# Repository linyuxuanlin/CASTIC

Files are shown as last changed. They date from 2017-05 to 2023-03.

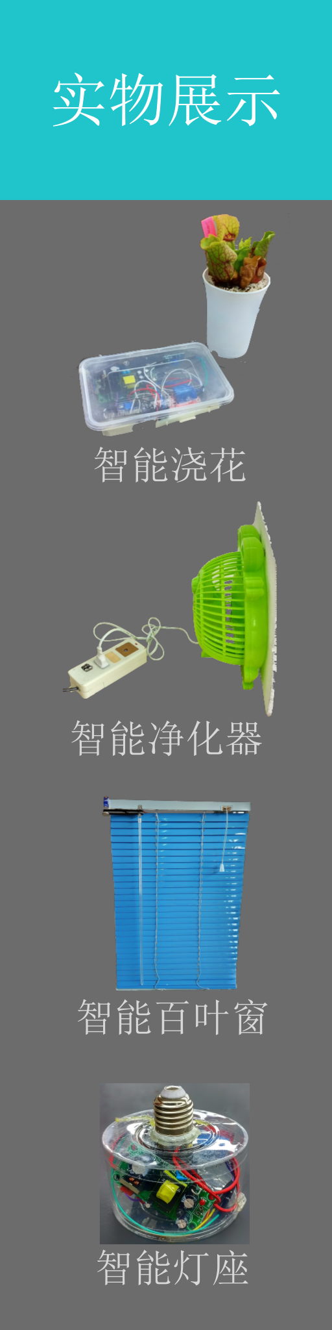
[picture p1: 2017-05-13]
展示宣传画/默认标题--设计创建于创客贴 (2).png

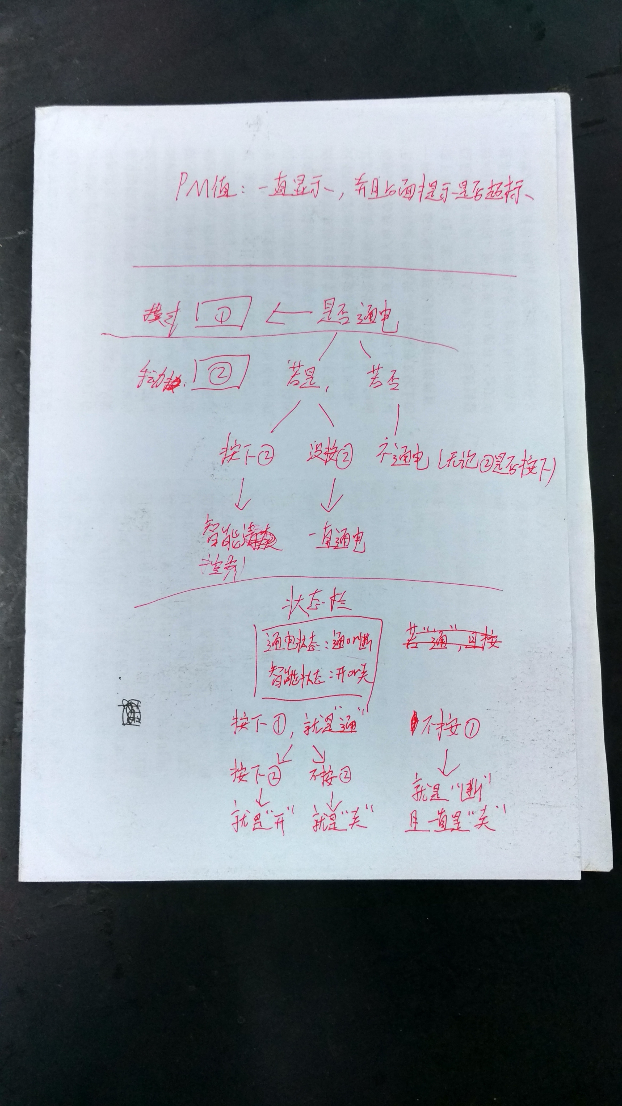
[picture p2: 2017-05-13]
废纸篓/想法构思/IMG_20161125_222327_HDR.jpg

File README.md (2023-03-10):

17年3月17日，我在广州执信中学参加了第32届科创省赛。
## 项目经过
* 项目开始于一年前。因为是团队与自己都从没接触过的新硬件和平台，所以经常会遇到代码编译出错、硬件调试失败之类的问题。虽然很多时候问题显而易见，却需要考虑到每一个小的改动与以后可能出现的重大问题的间接联系。
* 比赛的前几天，成品突然无故出了问题，如果不解决的话，肯定连三等奖都拿不上。团队的协作攻关在此时起到了重要的作用，在比赛前一天终于顺利把问题根除了。
* 比赛的时候，尽量要脸皮厚一些。这样才能拉到评委和嘉宾来参观自己的项目。解说的时候也要注意一定的技巧，比如，评委有时会提出刁难性的问题。这时只能顺着他的话锋，委婉地提出自己的观点，如此留给评委的印象会好很多，直接关系到自己的评分。
* 做出来的成品也交给专利代理事务所申请了专利，因为比赛的需要和日后可能的用处。

### 附：比赛现场的照片




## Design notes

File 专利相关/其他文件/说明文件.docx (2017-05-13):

一种智能家居无损升级方案，包括：智能百叶窗、智能空气净化器、智能灯座

1.智能百叶窗套件：普通的家用百叶窗，可以通过简单地加装我们的通用性模块，实现智能控制。

其特征在于：包括带esp8266WiFi功能的主控板(1)、DHT11温湿度传感器(2)、雨水传感器(3)、手动上升按钮(4)、手动下降按钮(5)、自动模式按钮(6)、自动状态指示灯(7)、控制百叶窗开合的舵机(8)。

主要功能：

1.通过检测空气湿度并判断是否下雨，自动控制百叶窗开合，保护家居；

2.百叶窗升级套件能够连接上家中的WiFi，使手机端app能够在任何地方看到百叶窗的开合状态、模式等并实现控制。手机app端能够获取家中的空气湿度，判断是否下雨并通知用户进行相关操作

3.百叶窗升级套件包含手动按钮(4、5)，分4个开合档位，可手动调节百叶窗开合程度

工作原理：

主控板(1)通过板载esp8266连接上WiFi，温湿度传感器(2)和雨水传感器(3)获取当前空气温湿度，按钮(4、5)为用户提供手动操作功能，舵机(8)控制百叶窗开合

2.智能空气净化器套件：包括智能插座、空气滤网。适用于大多数普通的家用电风扇改装成空气净化器。

其特征在于：包括带esp8266WiFi功能的主控板(1)、PM2.5传感器(2)、220v—5v降压模块(3)、继电器模块(4)、插座开关指示灯(5)。

主要功能：

插座能够连接上家中的WiFi，在手机app端能够实时显示家中PM2.5浓度值，判断是否超标并通知用户进行相关操作；自动模式下，如果空气浓度超标，智能插座能够使带有滤网的风扇运行，实现智能空气净化的目的

工作原理：

降压模块(2)将市电转换成5v电压为主控板(1)供电，主控板(1)通过板载esp8266连接上WiFi，PM2.5传感器(2)检测当前空气中的PM2.5浓度值，主控板(1)通过继电器(3)控制插座开关，指示灯(5)根据插座状态相应开关

3.智能灯座套件：普通的灯泡，可以通过加装通用性的智能灯座，实现智能控制。

其特征在于：包括带esp8266WiFi功能的主控板(1)、220v—5v降压模块(2)、继电器模块(3)、普通的灯泡(4)。

主要功能：智能灯座能够连上家中WiFi，实现手机app端的智能控制

工作原理：降压模块(2)将市电转换成5v电压为主控板(1)供电，主控板(1)通过板载esp8266连接上WiFi，主控板(1)通过继电器(3)控制灯泡开关

联动功能：

1.影院模式：当用户在手机app端点击影院模式时，百叶窗自动关合，空气净化器打开，灯泡熄灭，为用户模拟影院的环境

优势：

1.无损化：不破坏原有的家居结构，在其基础上加以智能化；

2.通用化：套件适配于大多数老旧家居结构

3.低成本化

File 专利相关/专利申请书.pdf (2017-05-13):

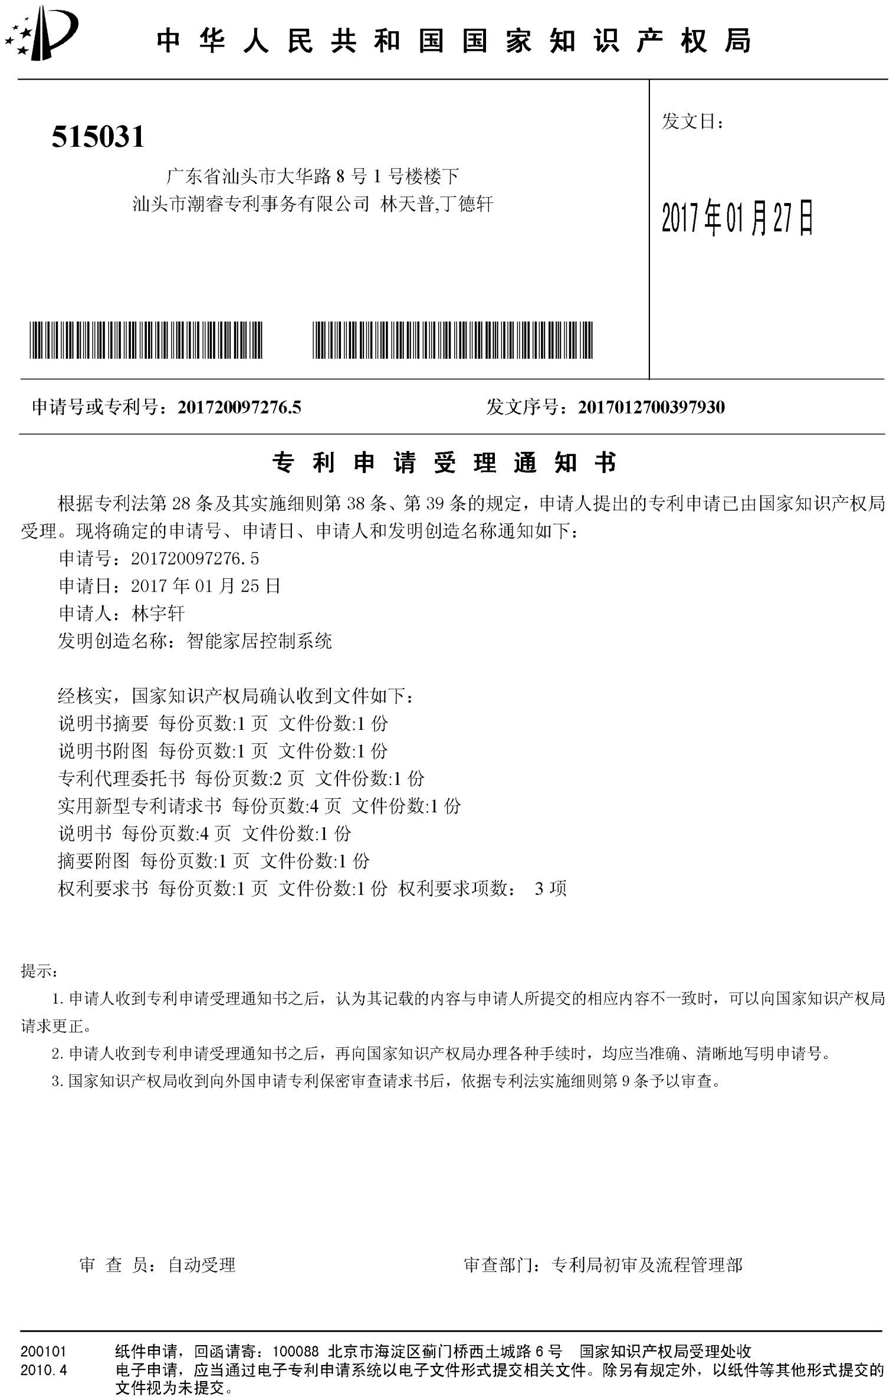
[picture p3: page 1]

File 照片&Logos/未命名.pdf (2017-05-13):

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

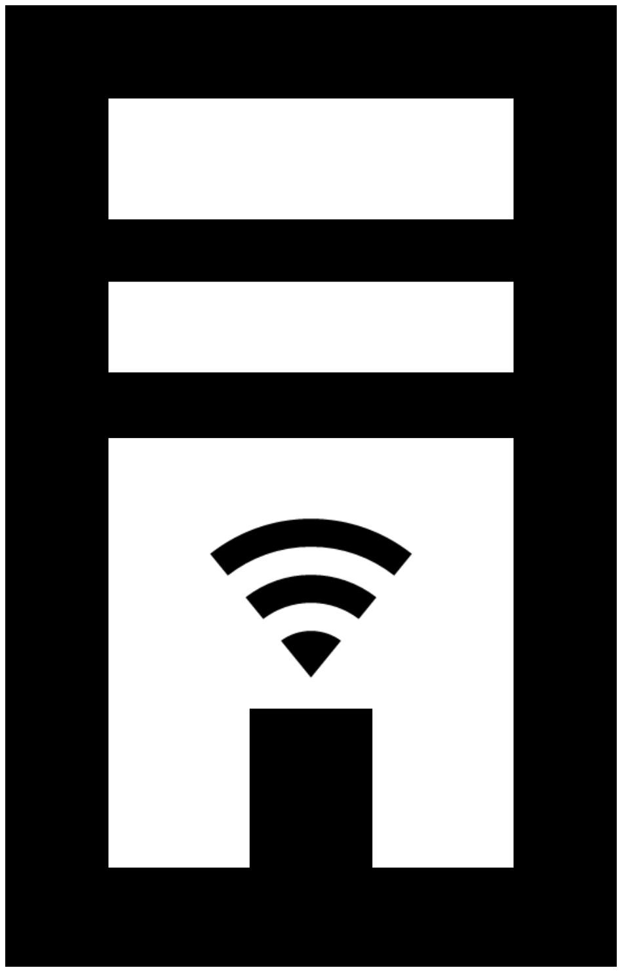
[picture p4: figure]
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

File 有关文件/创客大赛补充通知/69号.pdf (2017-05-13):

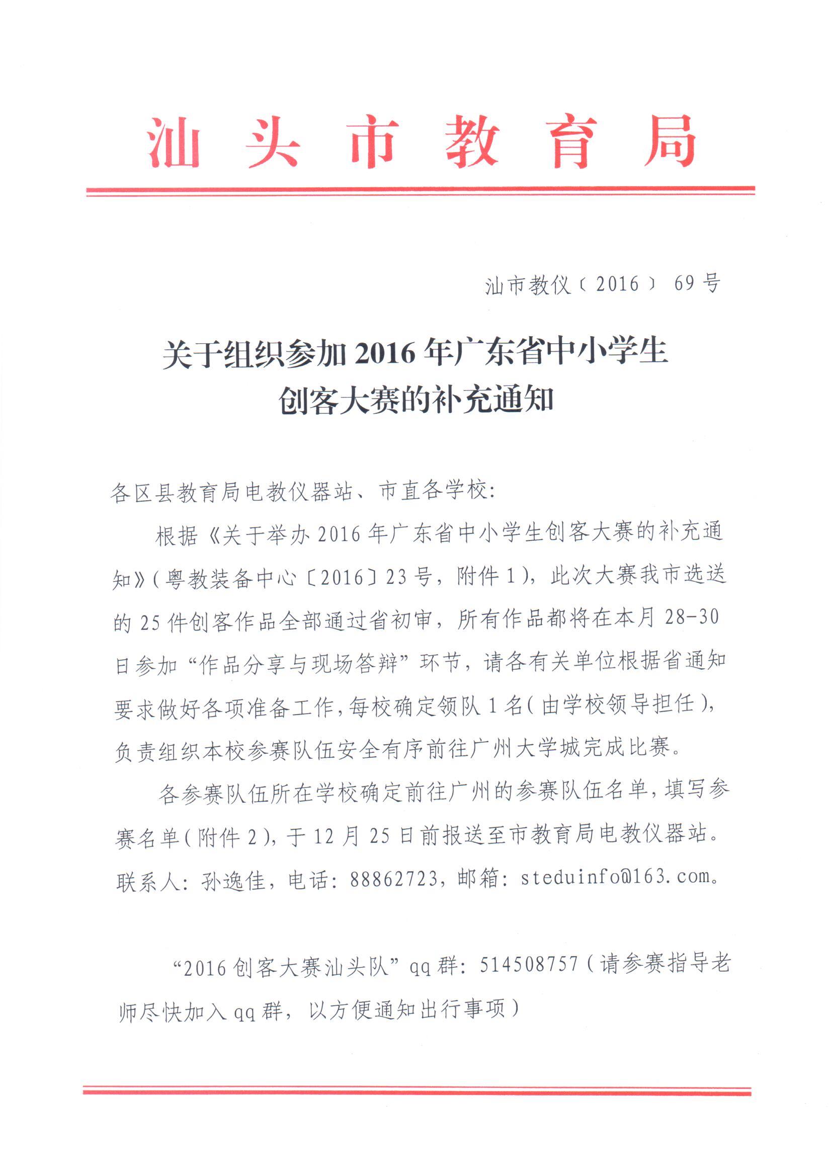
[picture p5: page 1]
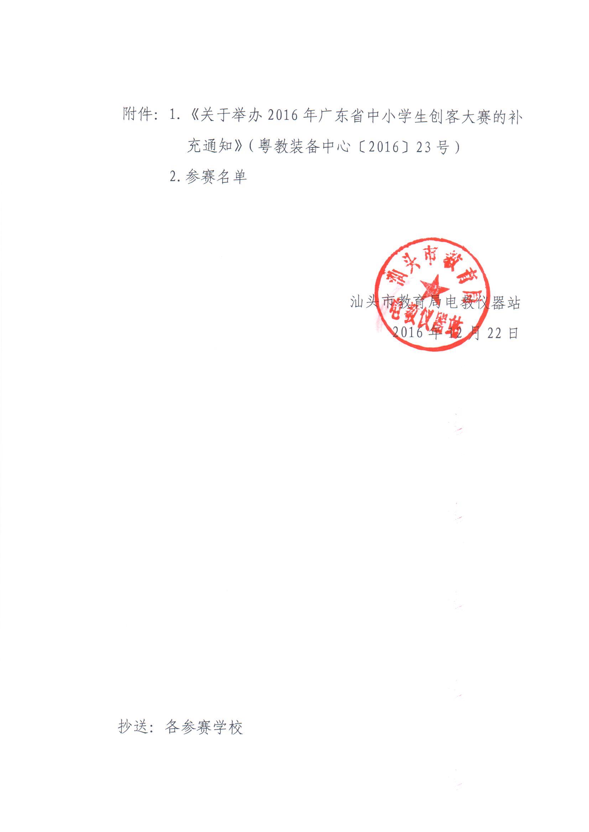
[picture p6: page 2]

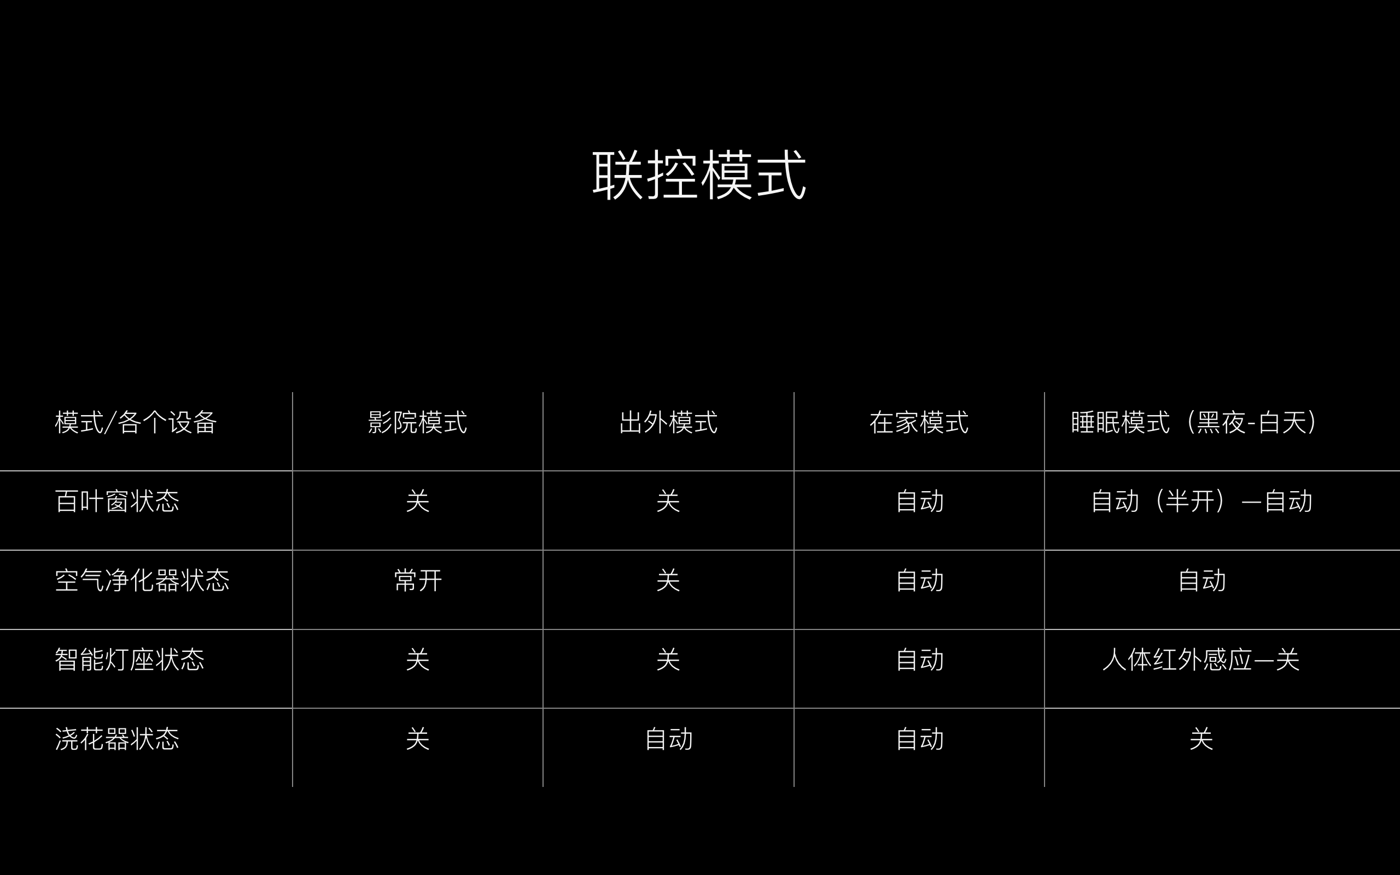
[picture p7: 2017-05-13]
联控模式.png

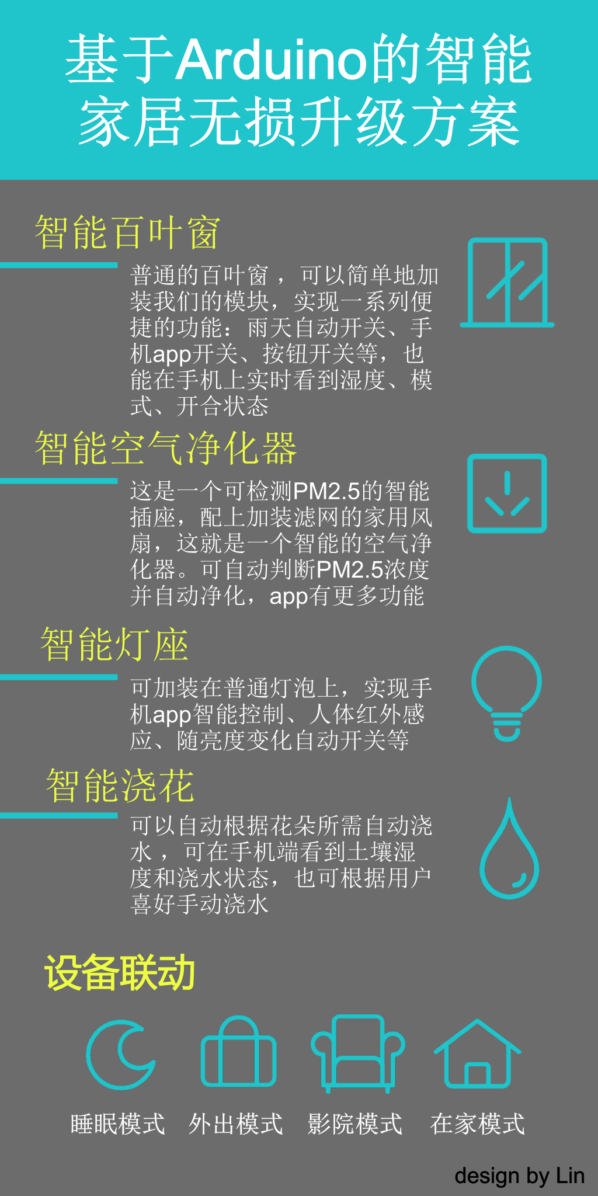
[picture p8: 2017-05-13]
展示宣传画/默认标题--设计创建于创客贴 (1).png

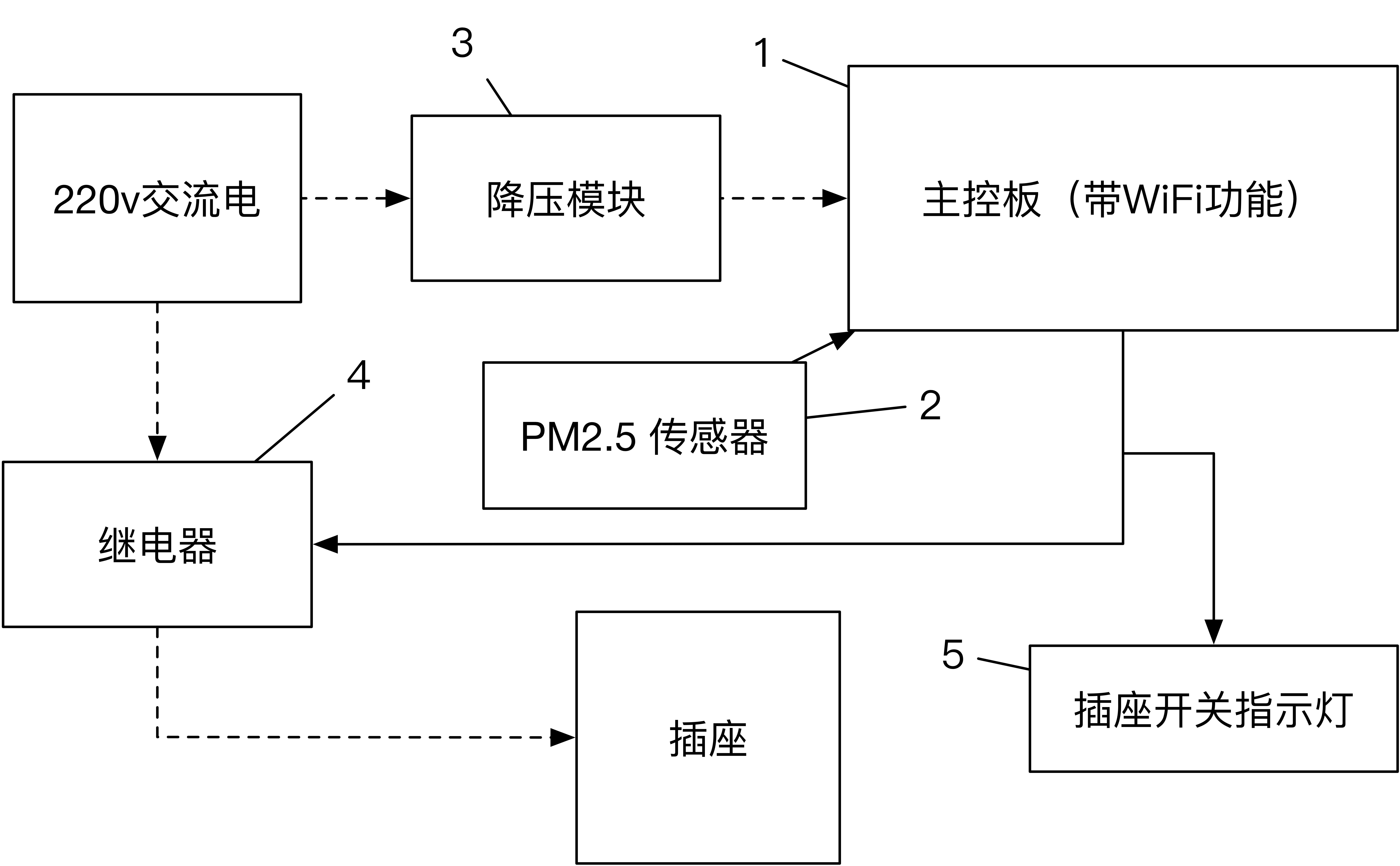
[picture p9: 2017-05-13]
专利相关/其他文件/插座流程图.png

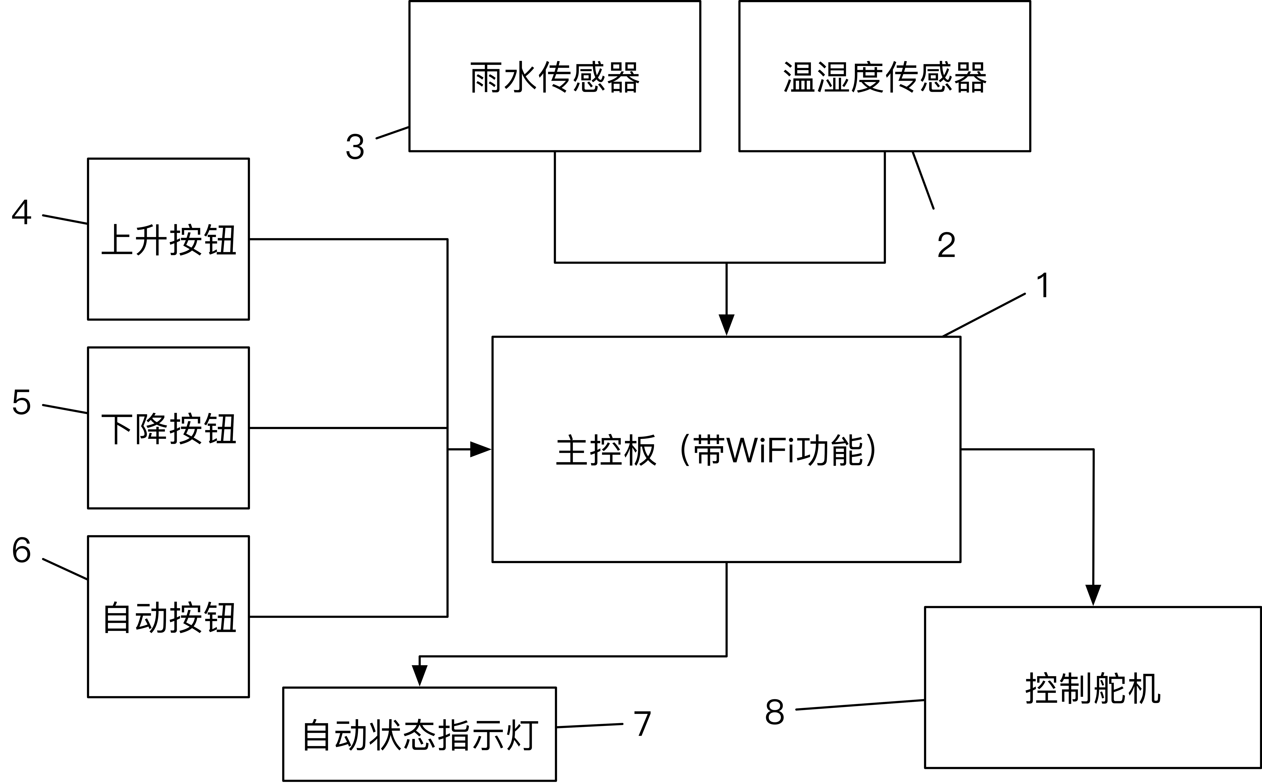
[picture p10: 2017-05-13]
专利相关/其他文件/百叶窗流程图.png

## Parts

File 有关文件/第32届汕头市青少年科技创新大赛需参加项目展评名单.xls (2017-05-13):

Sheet: 作品分类物理工程类
第32届汕头市青少年科技创新大赛项目展评名单（实践类）
申报单位：
项目编码 | 项 目 名 称 | 作 者 | 科技创新成果 | 所在学校 | 学历或年级 | 辅导教师 | 所属区域
A1 | 表面张力演示教具 | 陈新灏,郑枫辉 | 物理学 | 潮南区成田高级中学 | 高中 | 林彤妍 | 潮南区
A2 | 耳机绕线器 | 欧阳梓洪 | 物理学 | 潮南区两英中学 | 高中 | 陈丽玲 | 潮南区
A3 | 遥控重心平衡车 | 姚泽鹏 郑曼仪 陈潮锐 | 工程学 | 汕头市潮阳黄图盛中学 | 高中 | 陈镇宏 | 潮阳区
A4 | 诸葛连弩 | 陈新演 林自源 陈信宇 | 工程学 | 汕头市潮阳黄图盛中学 | 高中 | 李丽华 | 潮阳区
A5 | 四联一控开关 | 姚玫琼 | 工程学 | 汕头市潮阳黄图盛中学 | 高中 | 陈镇宏 | 潮阳区
A6 | 对生活慢速度陶瓷过滤器的改进 | 罗翊瀚 | 物理学 | 汕头市潮阳实验学校 | 初中 | 吴楷盛 王兴德 | 潮阳区
A7 | 多功能实时体温仪 | 刘煜凯 | 物理学 | 汕头市潮阳实验学校 | 初中 | 金邵涛 | 潮阳区
A8 | 粉笔粉尘环保收集盒 | 陈清钿 | 物理学 | 汕头市澄海莱芜中学 | 初中 | 许海得 | 澄海区
A9 | 可充电直流手电钻 | 杜中昊 | 物理学 | 澄海坝头中学 | 初中 | 王哲标 章逢媛 | 澄海区
A10 | 自动壁障吸尘器小汽车 | 蔡林宏 | 工程学 | 澄海凤翔中学 | 初中 | 林晓铭 李龙彦 | 澄海区
A11 | 安装超载自动报警器的货船 | 王思烁 程汤海 李穆羲 | 物理学 | 澄海区莲东中学 | 初中 | 肖锦豪 肖琼伟 | 澄海区
A12 | 地下车库进水报警及自动排水装置 | 陈勋 郭之泳 王思捷 | 物理学 | 澄海实验高级中学 | 高中 | 洪秋鹏 陈培顺 | 澄海区
A13 | 老年人服药提醒装置 | 刘伟雄 王镇顺 林裕川 | 物理学 | 澄海实验高级中学 | 高中 | 洪秋鹏 陈培顺 | 澄海区
A14 | 多功能卫浴柜 | 王锶林 林树怀 | 工程学 | 澄海职业技术学校 | 中专 | 蔡卫斌 | 澄海区
A15 | 新型主机架 | 张乐明 王奕标 | 工程学 | 澄海职业技术学校 | 中专 | 蔡卫斌 吴桐 | 澄海区
A16 | 改进型浴室用一氧化碳报警器 | 林云发 | 工程学 | 澄海职业技术学校 | 中专 | 陈骏鑫 | 澄海区
A17 | 液体折射率测量仪 | 陈炜斌 | 物理学 | 汕头市澄海澄华中学 | 高中 | 蔡松翰 | 澄海区
A18 | 预防电线老化引发火灾报警器 | 崔龙涛 | 物理学 | 汕头市澄海东里中学 | 高中 | 肖团平 吴群锋 | 澄海区
A19 | 抽油烟机定时控制器 | 崔龙涛 | 物理学 | 汕头市澄海东里中学 | 高中 | 肖团平 吴群锋 | 澄海区
A20 | 前进号（水陆两用车） | 李振佳 杨家明 王智祥 张俊杰 杜锦敏 | 工程学 | 汕头市澄海莲上中学 | 初中 | 李丽纯 郑少君 黄树发 | 澄海区
A21 | 燃气炉热量回收利用装置 | 余金宇 李少柯 杜梓 | 工程学 | 汕头市澄海莲阳中学 | 初中 | 杜扬顺 | 澄海区
A22 | 小型电动机模型 | 陈铉燚 | 物理学 | 汕头市澄海隆侨中学 | 初中 | 吴钢满 | 澄海区
A23 | 水果手机充电器 | 汕头市澄海苏湾中学 | 物理学 | 汕头市澄海苏湾中学 | 初中 | 陈志勇 | 澄海区
A24 | 停车智能辅助系统 | 蔡鸿博 许林铄 | 物理学 | 汕头市澄海兴华中学 | 初中 | 林仰海 | 澄海区
A25 | 光立方 | 林彦群 | 物理学 | 汕头市达濠中学 | 高中 | _王玥璇 | 濠江区
A26 | 塑料皮带传动电动车 | 杨端统 | 物理学 | 汕头市达濠中学 | 高中 | _王玥璇 | 濠江区
A27 | 清新脱俗小夜灯 | 陈忆璇、陈雪儿、陈晓滢 | 物理学 | 汕头市三河中学 | 初中 | 丁琼瑜 | 濠江区
A28 | 自动给水器 | 陈佩妍 | 物理学 | 汕头市三河中学 | 初中 | 丁琼瑜 | 濠江区
A29 | 观赏型净水器 | 陈轩琼 | 物理学 | 汕头市三河中学 | 初中 | 丁琼瑜 | 濠江区
A30 | 暗室手机投影仪 | 陈嘉忆、陈润林、陈泽锋 | 物理学 | 汕头市三河中学 | 初中 | 丁琼瑜 | 濠江区
A31 | 多功能梯子 | 洪普煜 | 工程学 | 汕头市东厦中学 | 初中 | 李帆 | 金平区
A32 | 一种不伤人的圆规 | 王晓佳 | 工程学 | 汕头市飞厦中学 | 初中 | 征茂德 郑弋 | 金平区
A33 | 一种可支持课堂教学或会议使用的无线音视频传输录放工具 | 蔡乐颀 | 物理学 | 汕头市聿怀初级中学 | 初中 | 钱桂校 | 金平区
A34 | 一种新型的一次性逃生防火服 | 郑派 | 物理学 | 汕头市聿怀初级中学 | 初中 | 钱桂校 | 金平区
A35 | 一种初中电学电路实验板的制作及其应用 | 张艺 | 物理学 | 汕头市聿怀初级中学 | 初中 | 钱桂校 | 金平区
A36 | 平抛记录仪的设计 | 杨禧元 林锷彬 郑一涵 | 物理学 | 汕头市聿怀中学 | 高中 | 曹志权 | 金平区
A37 | 关于二级水火箭发射控制的研制与定量分析 | 陈鸿彬 吕斯宏 | 物理学 | 汕头市聿怀中学 | 高中 | 曹志权 | 金平区
A38 | 光污染的利用 | 黄俊豪 郑安妤 | 物理学 | 汕头市聿怀中学 | 高中 | 曹志权 | 金平区
A39 | 智能消防安全疏散指示系统 | 卢灿、林哲斯、曾绮娜 | 工程学 | 汕头市林百欣科学技术中等专业学校 | 中专 | 陈庭照 杨应彬 王敏辉 | 林百欣科技中专
A40 | 车辆船舶限高通行智能控制系统 | 郭嘉烽 王沛锋 廖静莹 | 工程学 | 汕头市林百欣科学技术中等专业学校 | 中专 | 王敏辉 张文军 | 林百欣科技中专
A41 | 机动车涉水安全提醒智能系统 | 陈晓斌 黄培伟 卢妍 | 工程学 | 汕头市林百欣科学技术中等专业学校 | 中专 | 陈丽霞 王敏辉 | 林百欣科技中专
A42 | “以热治热”汽车环保排风扇 | 许锦丰、邹志鹏、谢萱 | 工程学 | 汕头市林百欣科学技术中等专业学校 | 中专 | 陈明文、何焕民、郑向雯 | 林百欣科技中专
A43 | 基于多媒体系统的打开车门预警装置 | 杨佳锐 姚亮 罗晴 | 工程学 | 汕头市林百欣科学技术中等专业学校 | 中专 | 何焕民 陈明文 蔡欣榕 | 林百欣科技中专
A44 | 汽车磁性万向工作灯 | 肖哲 | 物理学 | 广东第二师范学院龙湖附属中学 | 高中 | 林克生 | 龙湖区
A45 | 斯特林发动机探究演示 | 刘悦友 | 物理学 | 广东第二师范学院龙湖附属中学 | 高中 | 林琳 | 龙湖区
A46 | 我的“神舟一号” | 谢智博 | 物理学 | 汕头龙湖区嘉晋蓝天学校 | 小学 | 洪晓惠 | 龙湖区
A47 | 简易模拟全息投影成像系统 | 吴锴涵、蔡幼姗、纪珂 | 物理学 | 汕头市蓬鸥中学 | 初中 | 郑加荣 | 龙湖区
A48 | 自制光照强度测量装置及应用 | 刘权泳、李增、许梓堉 | 物理学 | 汕头市蓬鸥中学 | 初中 | 郑加荣 | 龙湖区
A49 | 双孔节能水盆 | 翁行 | 物理学 | 汕头市世贸实验学校 | 初中 | 黄新希、王少璜_、肖育霞 | 龙湖区
A50 | 汽车全自动节能吸尘器 | 陈煜佳 | 物理学 | 汕头市世贸实验学校 | 初中 | 黄新希 芮少銮 | 龙湖区
A51 | 晴雨天智能环保晾衣架 | 陈煜佳 | 物理学 | 汕头市世贸实验学校 | 初中 | 黄新希 芮少銮 | 龙湖区
A52 | 做功改变内能演示器 | 谢韵芝 | 物理学 | 汕头市新溪中学 | 初中 | 周树君 | 龙湖区
A53 | 便携式自动穿戴下肢辅助行走人体动力外骨骼系统 | 黄扬 | 工程学 | 汕头市金山中学 | 高中 | 杨时立 | 汕头金中
A54 | 多功能鞋底 | 林堉 | 工程学 | 汕头市金山中学 | 高中 | 杨时立 | 汕头金中
A55 | 自行车车把式打气筒 | 杜泽隆 | 工程学 | 汕头市金山中学 | 高中 | 杨时立 | 汕头金中
A56 | 自制太阳光谱仪 | 李锶铎 黄旭佳 | 物理学 | 汕头市金山中学 | 高中 | 朱潇剑 | 汕头金中
A57 | 中学生利用生活材料探究液体沸点与压强的关系 | 刘易恺 | 物理学 | 汕头市金山中学 | 高中 | 朱潇剑 | 汕头金中
A58 | 宇宙传记——黑洞 宇宙模型 | 黄植泓 | 物理学 | 汕头市金山中学 | 高中 | 杨时立 | 汕头金中
A59 | 无线便携式光电门 | 杨俊涛、谢琳、张晓珊 | 物理学 | 广东汕头华侨中学 | 高中 | 肖亮松，尤立娟，杨嘉瑞 | 汕头侨中
A60 | 基于arduino平台对传统家具的无损智能化升级套装 | 林宇轩 林沛杰 汤泽强 | 工程学 | 汕头市第一中学 | 高中 | 林卓睿 李溢滨 袁博 | 汕头一中
A61 | 电磁驱动和电磁阻尼综合演示仪 | 蔡家丰 冷世超 李少盈 | 物理学 | 汕头市第一中学 | 高中 | 林菁 陈进来 | 汕头一中
A62 | 听光实验探究及其应用¬¬——光琴 | 陈吉淳 陈晓娜 许强滨 | 物理学 | 汕头市第一中学 | 高中 | 陈柳娜 李伟坚 | 汕头一中
A63 | 神奇的光现象——激光干涉衍射演示仪 | 黄景荣 | 物理学 | 汕头市实验学校 | 高中 | 黄晓菲、肖晓星 | 市实

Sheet: 作品分类技术与设计、物质科学类
第32届汕头市青少年科技创新大赛项目展评名单（技术与设计、物质科学类）
申报单位：
项目编码 | 项 目 名 称 | 作 者 | 科技创新成果 | 所在学校 | 学历或年级 | 辅导教师 | 所属区域
B1 | 新型饮料瓶 | 廖敏希 | 技术与设计 | 汕头市潮南实验学校 | 小学 | 梁辉 | 潮南区
B2 | 可伸缩的方便碗 | 张豫东 | 技术与设计 | 汕头市潮南实验学校 | 小学 | 梁辉 | 潮南区
B3 | 多功能伸缩性晾衣架 | 王烁麒 | 技术与设计 | 澄海区汇璟实验小学 | 小学 | 王绵昭 | 澄海区
B4 | 家庭轿车前盲区（含AB柱盲区）解决方法 | 卢晓青 卢狄含 | 技术与设计 | 汕头市澄海北港华侨小学 | 小学 | 许海 | 澄海区
B5 | （家用）超声波水雾栽培 | 许轲轩 林旷怡 陈勤扬 | 技术与设计 | 汕头市澄海城北小学 | 小学 | 赵世僖 | 澄海区
B6 | 智能花盆保姆 | 陈奕焜 许漫馨 | 技术与设计 | 汕头市澄海城南小学 | 小学 | 赵世僖 | 澄海区
B7 | 智能清障机器人 | 林梓涵 | 技术与设计 | 汕头市澄海城南小学 | 小学 | 赵世僖 尤立伟 | 澄海区
B8 | 神龙小火箭 | 蔡炫嘉 许宙行 黄绎铭 | 技术与设计 | 汕头市澄海澄华小学 | 小学 | 沈观雄 陈彦芸 | 澄海区
B9 | 智能视力保护台灯 | 陈晓驰 | 技术与设计 | 汕头市澄海澄华小学 | 小学 | 陈妙玲 | 澄海区
B10 | 妈咪小帮手 | 许钢帆 蔡艺锋 | 技术与设计 | 汕头市澄海澄华中心小学 | 小学 | 高伟丹 李佩娇 李彦 | 澄海区
B11 | 一种简易触摸电子琴设计 | 许镕淇 | 技术与设计 | 汕头市澄海澄华中心小学 | 小学 | 高伟丹 郑楚如 | 澄海区
B12 | 自动感应遮雨帆 | 张欣琪 余永健 | 技术与设计 | 汕头市澄海东里小学 | 小学 | 李玲 张旭龙 | 澄海区
B13 | 感光自动窗帘 | 徐梓淮 沈擎 | 技术与设计 | 汕头市澄海东里小学 | 小学 | 李玲 张旭龙 | 澄海区
B14 | 电磁体验馆 | 张 悦 新 | 物质科学 | 汕头市澄海汇璟实验小学 | 小学 | 董雪萍 | 澄海区
B15 | 带液尽报警功能的静脉输液吊瓶悬挂器 | 江立宇 | 技术与设计 | 汕头市澄海区城南小学 | 小学 | 江 超 | 澄海区
B16 | 环保智能家居水资源再利用模型 | 林致睿 | 技术与设计 | 汕头市澄海区城南小学 | 小学 | 尤立伟 | 澄海区
B17 | 悬磁浮小制作—科技中国 | 金子孛 | 技术与设计 | 汕头市澄海仁美小学 | 小学 | 张燕惠 | 澄海区
B18 | 智能窗户系统 | 李凯楠 | 技术与设计 | 汕头市澄海实验小学 | 小学 | 陈万东 | 澄海区
B19 | 家用（兼车载）有害气体报警及净化一体机 | 蔡新怡 吴易萱 潘梓琳 | 技术与设计 | 汕头市澄海实验小学 | 小学 | 赵世僖 陈万东 王嗣泰 | 澄海区
B20 | 智能感温奶瓶（水杯） | 王俊淇 许琼月 许沐阳 | 技术与设计 | 汕头市澄海实验小学 | 小学 | 赵世僖 陈万东 王嗣泰 | 澄海区
B21 | 压电式横闯预警系统 | 王羽睿 魏微 王泽奇 | 技术与设计 | 汕头市澄海实验小学 | 小学 | 陈万东 | 澄海区
B22 | 后备箱替收员（小论文） | 叶子烁 | 技术与设计 | 汕头市长安小学 | 小学 | 叶斌 | 金平区
B23 | 虚空射虎—体感灯谜游戏控制装置 | 陈治瑞、姚柏言、杨珂铄 | 技术与设计 | 汕头市长厦小学 | 小学 | 李铠嘉、黄靖晖、陈晓燕 | 金平区
B24 | 背包疲劳按摩缓解器 | 郭子铭 | 技术与设计 | 汕头市长厦小学 | 小学 | 李铠嘉、纪欣欣 | 金平区
B25 | 我为创文做贡献—会唱歌说话的太阳能自动感应垃圾桶 | 黄悦霖、吉一灵 | 技术与设计 | 汕头市长厦小学 | 小学 | 李铠嘉、陈晓玲、黄靖晖 | 金平区
B26 | 健康中国，从我“坐”起——智能椅子 | 李诗韵、郭子铭、钟语欣 | 技术与设计 | 汕头市长厦小学 | 小学 | 李铠嘉、黄靖晖、纪欣欣 | 金平区
B27 | 音乐楼梯2.0（Scratch版本) | 吉一灵、郭子铭、陈官睿 | 技术与设计 | 汕头市长厦小学 | 小学 | 李铠嘉、纪欣欣 | 金平区
B28 | 感应式八音琴 | 钟语欣、钟浠彤 | 技术与设计 | 汕头市长厦小学 | 小学 | 李铠嘉、张哲佩、黄靖晖 | 金平区
B29 | 防止杯子被碰倒的护具 | 杨翊钦 | 技术与设计 | 汕头市长厦小学 | 小学 | 李铠嘉、纪欣欣 | 金平区
B30 | 挂耳式可折叠镜片夹 | 杨烨恺 | 技术与设计 | 汕头市长厦小学 | 小学 | 陈恋珠、许德城、杨嘉瑞 | 金平区
B31 | 可调节高度的枕头 | 汤芯铭 | 技术与设计 | 汕头市长厦小学 | 小学 | 李铠嘉、纪欣欣 | 金平区
B32 | 多用途吸管 | 钟浠彤、钟卓凡 | 技术与设计 | 汕头市长厦小学 | 小学 | 李铠嘉、姚文静、纪欣欣 | 金平区
B33 | 自制简易平板电脑支架 | 陈铠煌、陈铠烁 | 技术与设计 | 汕头市长厦小学 | 小学 | 李铠嘉、纪欣欣、陈晓燕 | 金平区
B34 | 虹吸现象演示器 | 郑悦孜 | 技术与设计 | 汕头市长厦小学 | 小学 | 李铠嘉、纪欣欣 | 金平区
B35 | 视频报警（提醒）装置Scratch版 | 彭绮涵、吴皓宇 | 技术与设计 | 汕头市长厦小学 | 小学 | 李铠嘉、纪欣欣 | 金平区
B36 | 新型涂改带 | 陈炜楷 | 技术与设计 | 汕头市大华路第一小学 | 小学 | 曾冰娱 | 金平区
B37 | 带卷轴两用纸盒 | 洪泽炀 | 技术与设计 | 汕头市东方小学 | 小学 | 李楠 | 金平区
B38 | 自动宠物喂食器 | 杨源 | 技术与设计 | 汕头市东方小学 | 小学 | 李楠 | 金平区
B39 | 光纤照明扫把 | 周子健、吴泽峰 | 技术与设计 | 汕头市东方小学 | 小学 | 李楠 | 金平区
B40 | 紫外线洗漱用品风干消毒器（第2代） | 林广宇 | 技术与设计 | 汕头市东方小学 | 小学 | 李楠 | 金平区
B41 | 除“粘”扫地套装 | 余佳娴 | 技术与设计 | 汕头市东方小学 | 小学 | 李楠 | 金平区
B42 | 雾化降尘黑板 | 徐诗韵、徐诗婕 | 技术与设计 | 汕头市东方小学 | 小学 | 李楠 | 金平区
B43 | 抽取式纸巾盒自动托升装置 | 林潼瑶 | 技术与设计 | 汕头市东厦小学 | 小学 | 陈卓琪 | 金平区
B44 | 风力水陆两用车模型 | 陈泓楠 | 技术与设计 | 汕头市东厦小学 | 小学 | 陈卓琪 | 金平区
B45 | 带排水功能的火山喷发模型 | 陈泓楠 | 技术与设计 | 汕头市东厦小学 | 小学 | 陈卓琪 | 金平区
B46 | 新型拖地机 | 陈步青 | 技术与设计 | 汕头市东厦小学 | 小学 | 陈卓琪、顾若琳 | 金平区
B47 | 夜光手电筒 | 徐璟萱 | 技术与设计 | 汕头市东厦小学 | 小学 | 陈卓琪 | 金平区
B48 | 迷你吸尘器 | 吴昆晓 | 技术与设计 | 汕头市东厦小学 | 小学 | 马红棉、李丹琪 | 金平区
B49 | 迷你切割机 | 孙科翰 | 技术与设计 | 汕头市东厦小学 | 小学 | 马红棉、李丹琪 | 金平区
B50 | 水资源环保照明 | 林子腾 | 技术与设计 | 汕头市芙蓉小学 | 小学 | 张丽珊 | 金平区
B51 | 全自动智能牙签盒 | 陈靖潼 | 技术与设计 | 汕头市芙蓉小学 | 小学 | 张丽珊 | 金平区
B52 | 电磁晾衣棒 | 季金煌 | 技术与设计 | 汕头市芙蓉小学 | 小学 | 张丽珊 | 金平区
B53 | 双层调味壶 | 吴友亨 | 技术与设计 | 汕头市芙蓉小学 | 小学 | 张丽珊 | 金平区
B54 | 防作弊视力表 | 林佳慧 | 技术与设计 | 汕头市桂花小学 | 小学 | 柯泓 | 金平区
B55 | 抽取垃圾袋式实用垃圾桶 | 周理骞 | 技术与设计 | 汕头市桂花小学 | 小学 | 柯泓 | 金平区
B56 | 自动开关盖调料器 | 余浣珩 | 技术与设计 | 汕头市桂花小学 | 小学 | 柯泓 | 金平区
B57 | 实用雨衣 | 周俊君 | 技术与设计 | 汕头市桂花小学 | 小学 | 柯泓 | 金平区
B58 | 自动刷杯器 | 周怡彤 | 技术与设计 | 汕头市桂花小学 | 小学 | 柯泓 | 金平区
B59 | 《风神号太空航天飞机及配套的月球1号太阳能探测车》 | 黄昊 | 技术与设计 | 汕头市金龙小学 | 小学 | 李乐慧 李旭宁 | 金平区
B60 | 《遥控清洁船》 | 洪嘉超 洪嘉越 | 技术与设计 | 汕头市金龙小学 | 小学 | 袁黎珊 李旭宁 | 金平区
B61 | 《小小冷藏柜》 | 刘沐立 | 技术与设计 | 汕头市金龙小学 | 小学 | 黄奕纯 李旭宁 | 金平区
B62 | 环保简易吸尘器 | 周澄宇 | 技术与设计 | 汕头市金龙小学 |  | 翁丽芸 李旭宁 | 金平区
B63 | 防溢锅盖 | 陈乐欢 | 技术与设计 | 汕头市蓝天小学 | 小学 | 许燕绒 | 金平区
B64 | 遥控拖地车 | 袁泽豪 | 技术与设计 | 汕头市蓝天小学 | 小学 | 许燕绒 | 金平区
B65 | 节能发光空调 | 沈恭娈 | 物质科学 | 汕头市蓝天小学 | 小学 | 许惠洁 | 金平区
B66 | 变废为宝——简易捕鼠器 | 王嘉韩 | 物质科学 | 汕头市蓝天小学 | 小学 | 陈思妍 | 金平区
B67 | 太阳能水上自动打捞机 | 唐锦勋 | 物质科学 | 汕头市蓝天小学 | 小学 | 张静娟 | 金平区
B68 | 发光钥匙 | 吴昊展 | 物质科学 | 汕头市蓝天小学 | 小学 | 许惠洁 | 金平区
B69 | 带风扇的玩具车 | 陈思帆 | 物质科学 | 汕头市蓝天小学 | 小学 | 佘雪燕 | 金平区
B70 | 节能玩具太阳船 | 李享 | 物质科学 | 汕头市蓝天小学 | 小学 | 沈奕翔 | 金平区
B71 | 移动送餐车 | 翁乔、许钿茵 | 物质科学 | 汕头市蓝天小学 | 小学 | 谢晓婷 | 金平区
B72 | 洗刷刷神器 | 章宇欣 辛霖豌 | 技术与设计 | 汕头市私立广厦学校 | 小学 | 许楚文 | 金平区
B73 | 带槽毛笔架 | 邱钰莹 | 技术与设计 | 汕头市私立广厦学校 | 小学 | 许楚文 | 金平区
B74 | 小夜叉 | 陈一炀 | 技术与设计 | 汕头市外马路第三小学 | 小学 | 林永强 | 金平区
B75 | 定时冲水装置 | 刘子牧 | 技术与设计 | 汕头市外马路第三小学 | 小学 | 黄瑶珊 | 金平区
B76 | 炫炫小机器人 | 朱奕至 | 技术与设计 | 汕头市外马路第三小学 | 小学 | 刘玲蓉 | 金平区
B77 | 自动避障洒水刷地机器车 | 刘子牧 | 技术与设计 | 汕头市外马路第三小学 | 小学 | 黄瑶珊 | 金平区
B78 | 简易发电装置 | 蔡泓钊 | 技术与设计 | 汕头市外马路第三小学 | 小学 | 黄瑶珊 | 金平区
B79 | 环保浮力小帆船 | 柳宇钊 | 技术与设计 | 汕头市外马路第三小学 | 小学 | 林婷 | 金平区
B80 | 多功能电动小清洁棒 | 许哲桁 | 物质科学 | 汕头市外马路第三小学 | 小学 | 黄瑶珊 | 金平区
B81 | 一种底部可拆卸特殊物质盛装容器 | 陈俊驰 | 技术与设计 | 汕头市外马路第四小学 | 小学 | 陈泽龙 | 金平区
B82 | 《智能晾衣架》 | 林静宜 林曦 | 技术与设计 | 汕头市杏花第二小学 | 小学 | 黄妃娜 | 金平区
B83 | 《公交车扶手设计》 | 蔡怡文 郑丽如 | 技术与设计 | 汕头市杏花第二小学 | 小学 | 黄妃娜 | 金平区
B84 | 《公交车安全设计改进》 | 李南豪 许秩恺 | 技术与设计 | 汕头市杏花第二小学 | 小学 | 黄妃娜 | 金平区
B85 | 《多层衣架》 | 马晓丽 | 技术与设计 | 汕头市杏花第二小学 | 小学 | 黄妃娜 | 金平区
B86 | 隔热安全书包 | 吴烨 | 技术与设计 | 汕头龙湖区嘉晋蓝天学校 | 小学 | 卓晓君 | 龙湖区
B87 | 多功能拐杖 | 蔡睿哲 | 技术与设计 | 汕头龙湖区嘉晋蓝天学校 | 小学 | 黄婷姿 | 龙湖区
B88 | 儿童防溺水雨衣 | 佘澄锴 | 技术与设计 | 汕头龙湖区嘉晋蓝天学校 | 小学 | 黄婷姿 | 龙湖区
B89 | 自动避障小车 | 许立林 | 技术与设计 | 汕头龙湖区嘉晋蓝天学校 | 小学 | 林双 | 龙湖区
B90 | 精准书签 | 陈烨 | 技术与设计 | 汕头龙湖区嘉晋蓝天学校 | 小学 | 林双 | 龙湖区
B91 | 变废为宝——简易灯笼 | 黄梓洋 | 物质科学 | 汕头龙湖区嘉晋蓝天学校 | 小学 | 卓晓君 | 龙湖区
B92 | 简易记事书皮 | 汪旭 | 物质科学 | 汕头龙湖区嘉晋蓝天学校 | 小学 | 卓晓君 | 龙湖区
B93 | 变废为宝——简易笔筒收纳盒 | 林婷 | 物质科学 | 汕头龙湖区嘉晋蓝天学校 | 小学 | 卓晓君 | 龙湖区
B94 | 简易桌面吸尘器 | 潘一湃 | 物质科学 | 汕头龙湖区嘉晋蓝天学校 | 小学 | 黄婷姿 | 龙湖区
B95 | 闲置玩具零件的重新组合-音乐台灯风扇 | 陈思宇 | 物质科学 | 汕头龙湖区嘉晋蓝天学校 | 小学 | 黄婷姿 | 龙湖区
B96 | 一种普通电话机可用的视频聊天设备 | 邓沁林 张家源 | 技术与设计 | 汕头市龙湖区金阳小学 | 小学 | 廖驰 林琢勋 | 龙湖区
B97 | 简便“啪啪”杯座 | 池 倍 | 技术与设计 | 汕头市龙湖区龙湖小学 | 小学 | 吴 瑶 谢喜荣 | 龙湖区
B98 | 乖乖指甲钳 | 唐颖婕 | 技术与设计 | 汕头市龙湖区龙湖小学 | 小学 | 谢喜荣 吴 瑶 | 龙湖区

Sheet: 作品分类社科类
第32届汕头市青少年科技创新大赛项目展评名单（社科类）
申报单位：
项目编码 | 项 目 名 称 | 作 者 | 科技创新成果 | 所在学校 | 学历或年级 | 辅导教师 | 所属区域
C1 | 《精美小吊灯》 | 林伊桐 陈灿嘉 胡锦绣 | 行为与社会科学 | 汕头市澄海峰下小学 | 小学 | 陈冰如 | 澄海区
C2 | 《公益广告，公众行为的灯塔》 | 吴思敏 | 行为与社会科学 | 汕头市东方中学 | 高中 | 宋立强、 吴晓君 | 金平区
C3 | 可随身携带的便捷式水壶架 | 纪宏润、纪钡涵 | 行为与社会科学 | 汕头市汇翠小学 | 小学 | 吴少东 | 金平区
C4 | DIY创意伞 | 李译橦 | 行为与社会科学 | 汕头市金园实验中学 | 初中 | 杨伟佳 | 金平区
C5 | 可延伸衣架 | 陈培弘 | 行为与社会科学 | 汕头市外马路第三小学 | 小学 | 林婷 | 金平区
C6 | 关于青少年强迫倾向的相关研究 | 谢卓融 陈依星 张依凡 | 行为与社会科学 | 汕头市聿怀中学 | 高中 | 郑佳旋 | 金平区
C7 | 手机打车服务存在的问题以及未来发展状况 | 陈馥泓 杨湘仪 黄瀚仪 | 行为与社会科学 | 汕头市聿怀中学 | 高中 | 唐淳 | 金平区
C8 | 简易多功能挂钩 | 陈仪博 | 行为与社会科学 | 汕头龙湖区嘉晋蓝天学校 | 小学 | 洪晓惠 | 龙湖区
C9 | 博观而约取 厚积而薄发——借鉴港台经验，浅谈语文全国卷作文的几点思考 | 吴泽楠 林钡梓 杨冰 | 行为与社会科学 | 汕头市第一中学 | 高中 | 李曼娜 洪斌 | 汕头一中
C10 | 进城务工人员随迁子女家庭教育现状调查与问题研究——以汕头市中心城区为例 | 杨佳吉 倪乐琪 林尔楠 | 行为与社会科学 | 汕头市第一中学 | 高中 | 林武坚 彭丽 陈春湖 | 汕头一中
C11 | 汕头市高中生使用移动终端进行师生互动情况的调查与分析 | 陈思仰 张绮思 刘斯豪 | 行为与社会科学 | 汕头市第一中学 | 高中 | 林友帅 蔡洁瑜 骆长明 | 汕头一中
C12 | 创文路上看变化 ——汕头市金平区创文工作调研报告 | 陈衍雅 许淑莹 黄婷婷 | 行为与社会科学 | 汕头市第一中学 | 高中 | 陈岱如 欧隆旭 | 汕头一中
C13 | 品唐宋散文，悟人生哲理——以柳宗元、欧阳修和苏轼三人的散文为例分析 | 郑舒玲 詹若宜 李雪晴 | 行为与社会科学 | 汕头市第一中学 | 高中 | 郑楚丽 吴奕霖 庄玉宇 | 汕头一中
C14 | 创文背景下，汕头流动商贩管理模式探究——基于金砂公园疏导区的和新红荔市场的实证研究 | 余培烁 郑心滢 王海军 | 行为与社会科学 | 汕头市第一中学 | 高中 | 蔡燕娜 | 汕头一中
C15 | 中英文化差异对高中英语词汇教与学的影响及其对策 | 蔡恺南 陈映娜 李慧娟 | 行为与社会科学 | 汕头市第一中学 | 高中 | 陈娴玉 许思婷 李娴 | 汕头一中
C16 | 网络直播对当下青少年的影响 | 杨钦福 林裕泽 袁伟钊 | 行为与社会科学 | 汕头市第一中学 | 高中 | 林昭东 朱哲 肖燊 | 汕头一中
C17 | 歌以咏志，言为心声——基于高中生喜爱歌曲的LIWC分析的群体心理研究 | 陈泽涵 施炜君 | 行为与社会科学 | 汕头市第一中学 | 高中 | 郭敏玲 谢晓哲 洪斌 | 汕头一中
C18 | 汕头市高中生留学意愿及未来就业意向的调查研究 | 邓颖怡 谢贝贝 | 行为与社会科学 | 汕头市第一中学 | 高中 | 王逸敏 姚馥玫 陈玲玲 | 汕头一中
C19 | 大学生基层就业问题的研究 | 林于焜 黄泓昕 吴燕婷 | 行为与社会科学 | 汕头市第一中学 | 高中 | 陈春湖 林武坚 彭丽 | 汕头一中
C20 | 新媒体对青少年价值观念和道德塑造的影响 | 张静玟 刘基鹏 谢嘉洽 | 行为与社会科学 | 汕头市第一中学 | 高中 | 林筱婉 杨颖 姚俊龙 | 汕头一中

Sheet: 作品分类综合类
第32届汕头市青少年科技创新大赛项目展评名单（综合类）
申报单位：
项目编码 | 项 目 名 称 | 作 者 | 科技创新成果 | 所在学校 | 学历或年级 | 辅导教师 | 所属区域
D1 | 基于ASEB栅格分析法的丹樱生态园可持续发展研究 | 陈思蓁 黄镇涛 钱世铧 | 地球与空间科学 | 汕头市第一中学 | 高中 | 陈煖佳 | 汕头一中
D2 | 关于赫罗图与恒星内部核反应阶段的关系的研究 | 麦骁锐 | 地球与空间科学 | 汕头市聿怀初级中学 | 初中 | 李楠 陈婷婷 张虹 | 金平区
D3 | 大犬座VY的测光与变化研究 | 陈俊驰 | 地球与空间科学 | 汕头市外马路第四小学 | 小学 | 陈泽龙 | 金平区
D4 | 研究昴星团中亮星的颜色与昴星团其恒星温度以及其年龄的关系 | 梁碧婷 | 地球与空间科学 | 汕头市聿怀中学 | 高中 | 李楠、倪悦琳 | 金平区
D5 | 为什么星云在不同波段的滤镜观测中出现强弱不同的现象 | 成翊杨 | 地球与空间科学 | 汕头市金园实验中学 | 初中 | 杨伟佳 | 金平区
D6 | 中学生古生物爬行体重判断方法创新 | 张楚睿 | 动物学 | 汕头市金山中学 | 高中 | 杨时立 | 汕头金中
D7 | 不同水生植物对草金鱼美殖的影响 | 李沛锋 | 动物学 | 汕头市澄海中学 | 高中 | 周俊毅 | 澄海区
D8 | 妙笔生花——电解饱和食盐水实验的趣味性改进 | 陈宜珠 王彦淇 | 化学 | 汕头市澄海苏北中学 | 高中 | 朱少芬 | 澄海区
D9 | 乙烯实验室制法的探究和改进 | 蔡海诺 林佳辉 | 化学 | 汕头市实验学校 | 高中 | 彭晓霞 林妙娜 李冰 | 市实
D10 | 透明度随温度变化而改变的玻璃——基于气象瓶原理 | 周永奇 姚泽嘉 | 化学 | 汕头市聿怀中学 | 高中 | 张晓纯 谢沛翰 | 金平区
D11 | 基于“双支锥形瓶”的开创性设计及在高中化学实验中的应用研究 | 陈铿 陈嘉俊 蔡毓韵 | 化学 | 汕头市东厦中学 | 高中 | 陈雪芸 陈锐彬 | 金平区
D12 | 比较不同的清洗方法对去除日常食用水果表面亚硝酸盐的效果 | 谢思琦 林欣桐 林千禧 | 化学 | 汕头市聿怀中学 | 高中 | 郑冰煌 邢丽聪 | 金平区
D13 | 《“喝弱碱性水对身体更好？” ——19款常见瓶装水PH值评测》 | 张光胜、 池春森、 李桦欣 | 化学 | 汕头市东方中学 | 高中 | 陈彬嫔 | 金平区
D14 | 峡山大溪农业用水人工湿地净化系统的设计 | 吕俊佟、刘文欣、蔡裕琴 | 环境科学 | 潮南区东山中学 | 高中 | 吴浩钦、李楚楚 | 潮南区
D15 | 绿色环保蚊子（蟑螂）诱捕装置 | 林心乐 陈冰怡 | 环境科学 | 汕头市澄海湾头中学 | 初中 | 林金煜 | 澄海区
D16 | 食物赢家 | 陈琳佳、陈燕璇、陈哲依 | 环境科学 | 汕头市三河中学 | 初中 | 丁琼瑜 | 濠江区
D17 | 河段治淤—泥水分离装置 | 林哲行，郭思健 | 环境科学 | 汕头市实验学校 | 高中 | 陈华娟、纪瑛侨 | 市实
D18 | 从蟹壳中提取壳聚糖处理废水中苯酚 | 林妙婷、林振行 | 环境科学 | 汕头市实验学校 | 高中 | 徐泽欢、陈祺洵、王燕杰 | 市实
D19 | “烈火焚烧莫等闲”——探究世界能源大势下汕头发展清洁能源的方向 | 姚成杰、林璐、 卢艺 | 环境科学 | 汕头市聿怀中学 | 高中 | 杜小芝 | 金平区
D20 | 搜题软件对中学教育的影响研究 | 兰晓雪 陈铭 | 数学 | 汕头市第一中学 | 高中 | 吴少燕 肖菁 郑国冰 | 汕头一中
D21 | 高中学生数学成绩与数学学习习惯的调查分析 | 徐志豪 陈文杰 杨志远 | 数学 | 汕头市澄海中学 | 高中 | 郑俊和 | 澄海区
D22 | 数学在建筑中的形式与涵韵——以陈慈黉故居与汕头大学建筑为例 | 陈昱熹 蔡沐祥 杜斯奋 张坤鹏 | 数学 | 汕头市澄海中学 | 高中 | 郑泽萍 | 澄海区
D23 | 基于微信平台的数字化校园生活服务创新——校车上车点及路线设置 | 谢铭楷、王琦 | 数学 | 汕头市实验学校 | 高中 | 林静萍、胡晓敏、陈胡铿 | 市实
D24 | 简单四则运算、三角函数机械计算器 | 李庚佑、李佳恩 | 数学 | 汕头市东厦中学 | 高中 | 吴毅铭 纪晓薇 林昕 | 金平区
D25 | 《多功能圆规画角尺》 | 王鑫桂、 蔡檄 | 数学 | 汕头市东方中学 | 初中 | 张泽楷 | 金平区
D26 | 优化油柑果核油分提取工艺的初步探究 | 陈晞彤 、邱佳文 | 医药与健康学 | 汕头市实验学校 | 高中 | 徐泽欢、刘嘉芹、林彦欣 | 市实
D27 | 耳部按摩器 | 黄仰乐 | 医药与健康学 | 汕头市金园实验中学 | 初中 | 杨伟佳 | 金平区
D28 | 一种可变焦眼镜 | 杨一帆 | 医药与健康学 | 汕头市金园实验中学 | 初中 | 杨伟佳 | 金平区
D29 | 巧改“植物的呼吸作用产生二氧化碳”实验装置 | 程泽依 | 植物学 | 汕头市澄海兴华中学 | 初中 | 曾雄明 | 澄海区
D30 | 养生宠儿“水果酵素”真的养生吗？ | 姚梓涵、徐杰兰 | 植物学 | 汕头市实验学校 | 高中 | 徐泽欢、刘嘉芹、林彦欣 | 市实

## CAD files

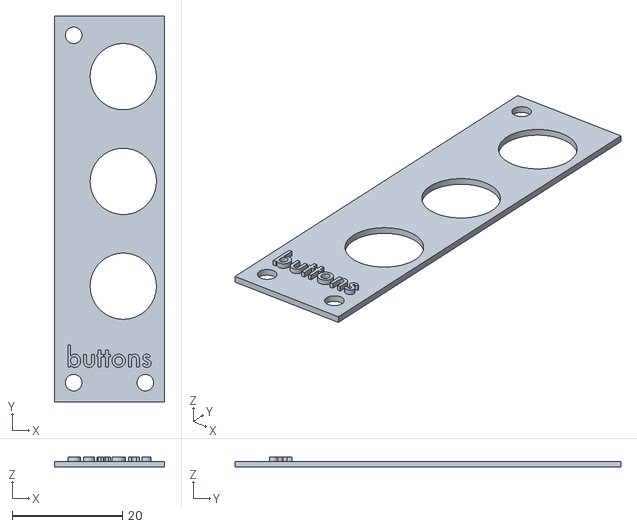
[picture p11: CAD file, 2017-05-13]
3D打印模型/button gai.stl
20.0 x 70.0 x 1.80

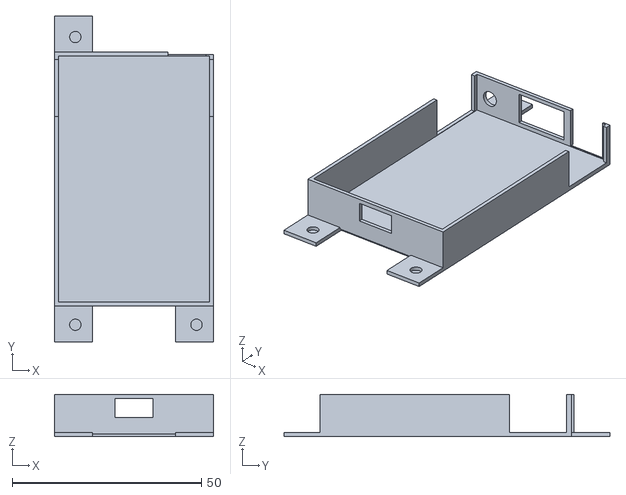
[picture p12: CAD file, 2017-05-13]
废纸篓/底座.stl
42.0 x 86.0 x 11.1

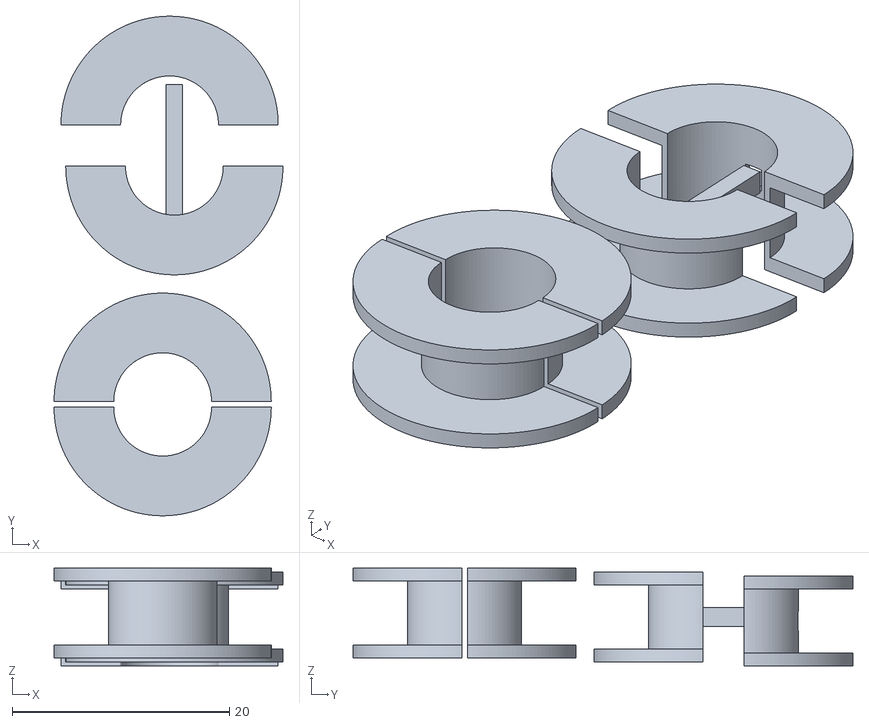
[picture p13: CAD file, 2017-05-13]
3D打印模型/旋钮2.stl
21.1 x 46.0 x 9.00

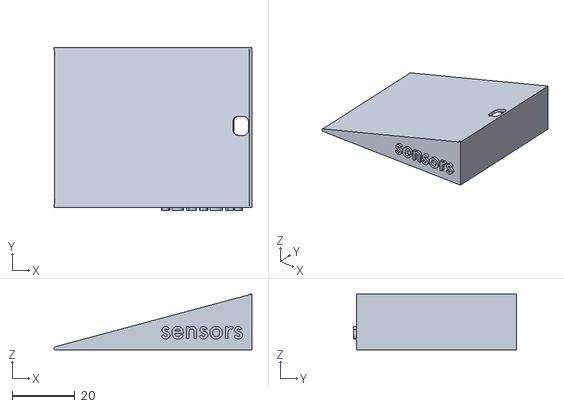
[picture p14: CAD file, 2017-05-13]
3D打印模型/传感器盒子.stl
63.0 x 52.0 x 17.8

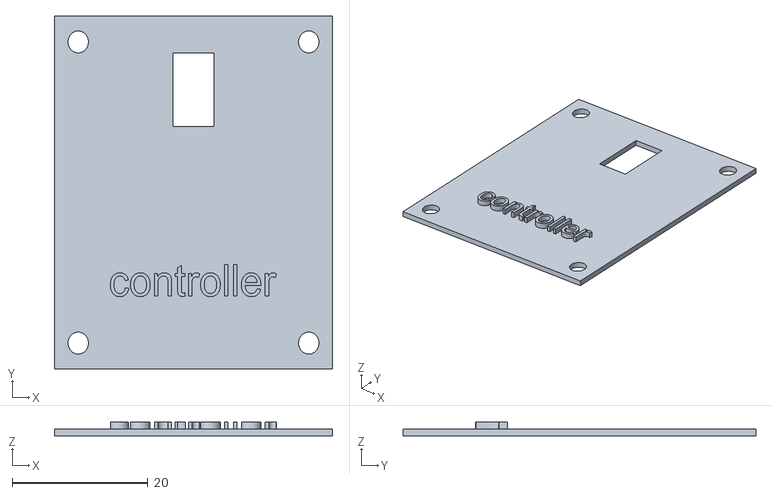
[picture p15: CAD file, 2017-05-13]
3D打印模型/主控盖子2.stl
41.0 x 52.0 x 2.00

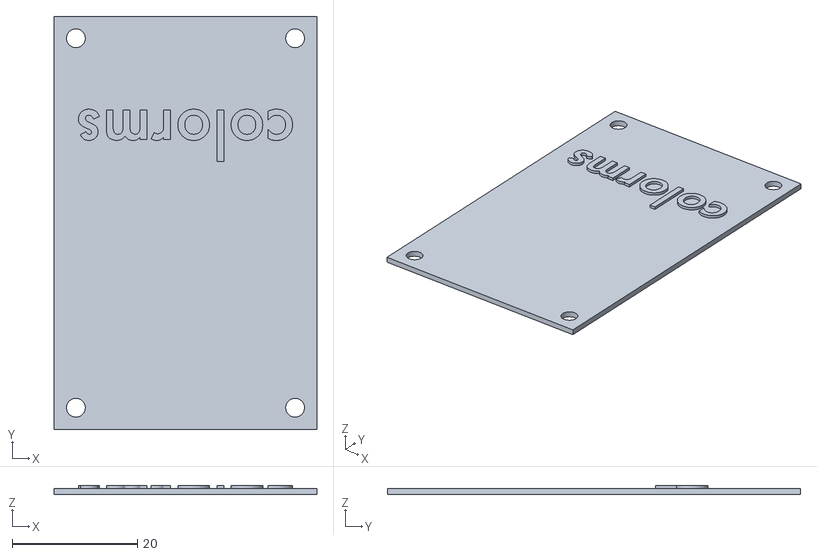
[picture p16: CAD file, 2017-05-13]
3D打印模型/盖子2.stl
42.0 x 66.0 x 1.50

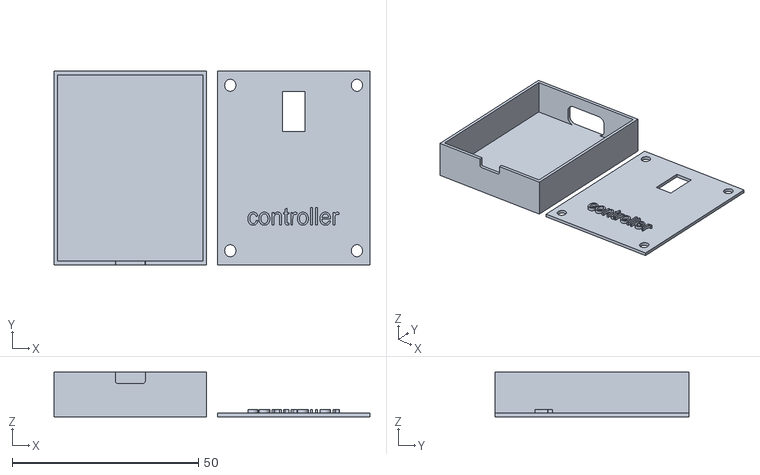
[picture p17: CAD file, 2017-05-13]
3D打印模型/主控2.stl
84.8 x 52.0 x 12.0

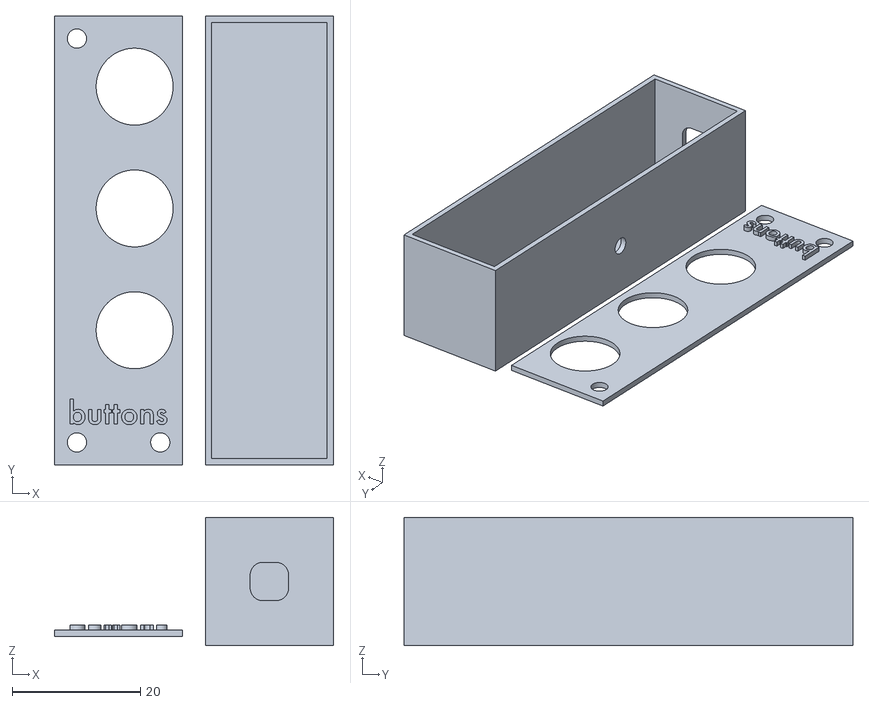
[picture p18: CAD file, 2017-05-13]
3D打印模型/按钮盒子.stl
43.5 x 70.0 x 20.0

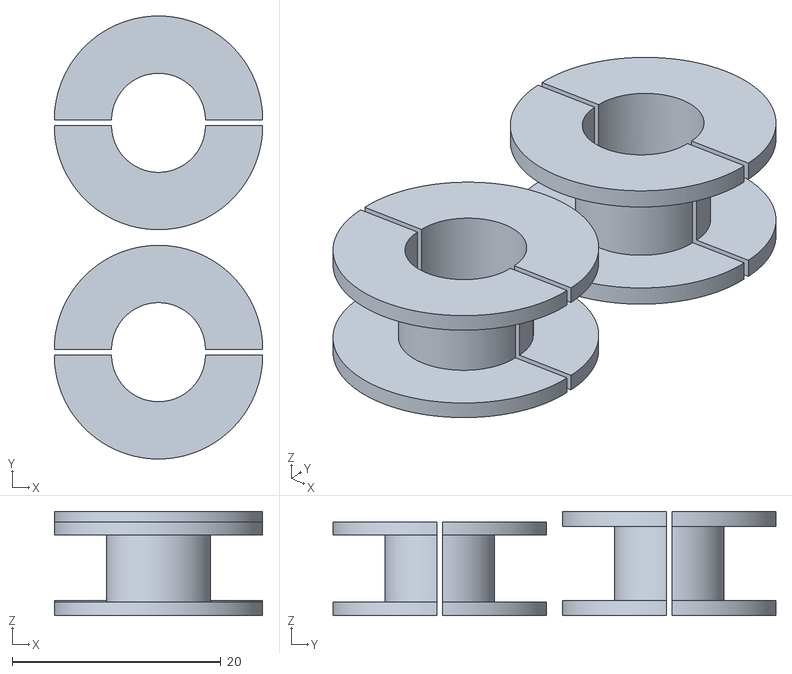
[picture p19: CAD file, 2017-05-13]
3D打印模型/xuan3.stl
20.0 x 42.5 x 10.0

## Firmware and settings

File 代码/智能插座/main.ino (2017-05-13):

#include <I2Cdev/I2Cdev.h>
#define PM_address "channel/widget2_0/data/dustval"
#define RECIEVE_address "channel/widget2_0/data/test"
#define BUTTONS_address    "channel/widget2_0/cmd/control"  
#define JUDGE_address    "channel/widget2_0/data/judge"  
int voutPin = A0;//灰尘传感器
int sensorled = D0;//灰尘传感器的LED检测
int relayPin = D1;//继电器
int test_led = D6;//测试的LED
int samplingTime = 280;//灰尘传感器取样时间
int deltaTime = 40;//灰尘传感器中断时间
int sleepTime = 9680;//让灰尘传感器休息一会儿
float voMeasured = 0;//采集数据
float calcVoltage = 0;//采集数据
int dustval ;//PM值
int x = 900 ;//闸值,超过:继电器吸合,反之
int a = 3 ;//继电器状态
void setup()
{
	IntoRobot.publish(RECIEVE_address,"hello");
	IntoRobot.subscribe(PM_address, NULL, PM_print_function);//描述PM值显示
    pinMode(relayPin, OUTPUT);	//继电器设为输出
	pinMode(test_led, OUTPUT);	//测试的LED设为输出
	pinMode(sensorled, OUTPUT);	//灰尘传感器的LED初始化
	digitalWrite(relayPin, LOW);	//继电器初始化,先设为断开
	digitalWrite(test_led, LOW);
	SerialUSB.begin(115200);
	IntoRobot.subscribe(BUTTONS_address, NULL, buttons_function);
	SerialUSB.println("hello");
}
void loop()
{
	PM_read_function();	//读取PM值
	//IntoRobot.publish(RECIEVE_address,"hello");
	IntoRobot.publish(PM_address,dustval);	//输出PM值 
	//relay_auto_function();	//继电器自动模式
	if(a==3){
	    relay_auto_function();
	    SerialUSB.println("auto");
	    IntoRobot.publish(RECIEVE_address,"自动模式");
	}
	if(a==2){
	    digitalWrite(relayPin, HIGH);
	    SerialUSB.println("relay on");
	    IntoRobot.publish(RECIEVE_address,"常开");
	}
	if(a==0){
	    digitalWrite(relayPin, LOW);
	    SerialUSB.println("relay off");
	    IntoRobot.publish(RECIEVE_address,"关闭");
	}
	if(dustval>900){
	    IntoRobot.publish(JUDGE_address,"PM浓度超标");
	}
	else{
	    IntoRobot.publish(JUDGE_address,"PM浓度正常");
	}
	delay(500);
}
void PM_read_function() //读取PM值
{
	digitalWrite(sensorled, LOW);
	delayMicroseconds(samplingTime);
	voMeasured = analogRead(voutPin);
	delayMicroseconds(deltaTime);
	digitalWrite(sensorled, HIGH);	//关LED
	delayMicroseconds(sleepTime);
	calcVoltage = (float)voMeasured * (5.0 / 1024.0);
	dustval = 1000 * 0.17 * calcVoltage - 0.1;
}
void relay_auto_function() //继电器自动模式
{
	if (dustval > x) //ON
	{
		digitalWrite(relayPin, HIGH);
	}
	else //OFF
	{
		digitalWrite(relayPin, LOW);
	}
	delay(1000);
}
void PM_print_function(uint8_t *payload, uint32_t len) //云端PM显示
{
}
void buttons_function(uint8_t *payload, uint32_t len)
{
	uint8_t SwitchKey;
	uint8_t SwitchKey2;
	aJsonClass aJson;
	aJsonObject *root = aJson.parse((char *)payload);
	if(root == NULL)
	{
		aJson.deleteItem(root);
		return;
	}
	aJsonObject *_switch = aJson.getObjectItem(root, "onbutton");
	if(_switch != NULL)
	{
		SwitchKey = atoi(_switch->valuestring);
	
		if(SwitchKey)
		{
			SerialUSB.println("onbutton");
			a=1;
		}
		else
		{
			SerialUSB.println("offbutton");
			a=0;
		}
	}
	aJsonObject *_switch2 = aJson.getObjectItem(root, "modebutton");
	if(_switch2 != NULL)
	{
		SwitchKey2 = atoi(_switch2->valuestring);
		if(a==1)
		{
			if(SwitchKey2)
			{
				SerialUSB.println("mode on");
				a=3;
			}
			else
			{
				SerialUSB.println("mode off");
				a=2;
			}
		}
	}
	else
	{
	}
	aJson.deleteItem(root);
}

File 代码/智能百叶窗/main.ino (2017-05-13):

#include <WidgetServo/WidgetServo.h> //调用舵机的库文件
#include <DHT11/dht11.h> //调用温湿度传感器的库文件
#define SMARTLIGHT_CMD_SWITCH    "channel/widget3_0/cmd/control"   //开关命令 
#define SMARTLIGHT_DATA_STATUS   "channel/widget3_0/data/light"    //开关状态
#define AUTO_STATUS   "channel/widget3_0/data/autostate"   //自动 
#define LEDPIN       D6 //定义测试灯泡控制引脚
#define UP           D1 //上升按钮
#define DOWN         D2 //下降按钮
#define AUTOBUTTON   D3 //自动按钮
#define water        D4 //雨水传感器
Servo myservo_A0;//定义舵机类
DHT11 senser_humiture_D0 = DHT11(D0);
int a=0;//控制开合的变量
int gate = 62;//湿度闸值
int middle = 87;//舵机中位值
boolean  buttonstate =0;//判断“自动”按钮状态的布尔变量
int updelay =1150 ;// 1/4上升时间 
int downdelay =1100 ; // 1/4上升时间 

void setup()
{
	pinMode(UP, INPUT_PULLUP);
	pinMode(DOWN, INPUT_PULLUP);
	pinMode(water,INPUT);
	pinMode(AUTOBUTTON, INPUT_PULLUP);
	myservo_A0.attach(D5);
	pinMode(LEDPIN, OUTPUT);
	IntoRobot.subscribe("channel/widget3_0/cmd/control", NULL, widget3_0Cb);
	IntoRobot.subscribe(SMARTLIGHT_CMD_SWITCH, NULL, smartLightSwitchCb);
	myservo_A0.write(middle);
	SerialUSB.begin(115200);
}
void loop()
{
	IntoRobot.publish("channel/widget3_0/data/humidity",senser_humiture_D0.ReadHumidity());
	if( a== 4)
	{
		IntoRobot.publish("channel/widget3_0/data/string","状态：关");
	}
	if( a== 0)
	{
		IntoRobot.publish("channel/widget3_0/data/string","状态：开");
	}
	if(digitalRead(AUTOBUTTON) == LOW)
	{
		buttonstate = !buttonstate;
		delay(200);
	}
	if (buttonstate==1 )
	{
		//自动模式
		digitalWrite(LEDPIN,HIGH);
		automode();
		delay(10);
		IntoRobot.publish(AUTO_STATUS,"自动模式");
	}
	if(buttonstate==0  )
	{
		//手动模式
        IntoRobot.publish(AUTO_STATUS,"手动模式");
		digitalWrite(LEDPIN,LOW);
		manual();
		delay(10);
	}
	SerialUSB.println(a);
}


void widget3_0Cb(uint8_t *payload, uint32_t len) //云端湿度显示
{
}
void ICACHE_FLASH_ATTR smartLightSwitchCb(uint8_t *payload, uint32_t len) //云端按钮
{
	uint8_t SwitchKey;
	//解析云平台下发的控制命令
	aJsonClass aJson;
	aJsonObject *root = aJson.parse((char *)payload);
	if(root == NULL)
	{
		aJson.deleteItem(root);
		return;
	}
	aJsonObject *_switch = aJson.getObjectItem(root, "switch1");
	if(_switch != NULL)
	{
		SwitchKey = atoi(_switch->valuestring);
		if(SwitchKey)
		{
			SerialUSB.println("on");
			IntoRobot.publish(SMARTLIGHT_DATA_STATUS,"1");
			down();
			down();
			down();
			down();
		}
		else
		{
			SerialUSB.println("off");
			IntoRobot.publish(SMARTLIGHT_DATA_STATUS,"0");
			up();
			up();
			up();
			up();
		}
	}
	aJson.deleteItem(root);
}
void ICACHE_FLASH_ATTR manual() //手动模式
{
	if(digitalRead(UP) == LOW)
	{
		up();
	}
	if(digitalRead(DOWN) == LOW)
	{
		down();
	}
}
void  ICACHE_FLASH_ATTR automode() //自动模式
{
	if (senser_humiture_D0.ReadHumidity()>gate && digitalRead(water==0))
	{
		down();
	}
	if (senser_humiture_D0.ReadHumidity()<(gate)&& digitalRead(water==1))
	{
		up();
	}
	else
	{
	}
	delay(10);
}
void  ICACHE_FLASH_ATTR up() //上升的函数
{
	if (a<4)
	{
		a++;
		myservo_A0.write(164);
		delay (updelay);
		myservo_A0.write(middle);
	}
}
void  ICACHE_FLASH_ATTR down() //下降的函数
{
	if (a>0)
	{
		a--;
		myservo_A0.write(0);
		delay (downdelay);
		myservo_A0.write(middle);
	}
}

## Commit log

2017-05-13 更新专利文件
2017-05-21 最新的论文
2017-05-28 更新的论文
2017-08-12 个人信息打码
